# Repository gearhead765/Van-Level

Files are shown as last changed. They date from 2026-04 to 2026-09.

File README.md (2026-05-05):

# Van Level

## Overview

ESP32 Based digital level to display leveling information for a camper van. This originally started as an ESPHome application however, the requirement to have Home Assistant running on your phone or tablet in order to see the leveling information was cumbersome.  It was decided that displaying the information on a simple web page, instead of a Home Assistant Lovelace overview, would be much easier to use.  However, there is also a [Home Assistant Dashboard](HOMEASSISTANT.md) setup available.

This app displays a simple webpage with a graphic of a camper van showing the amount of wheel lift (blocking) needed under each tire to level the van.  Included is the *Van Level* app, Kicad PCB files, and Solidworks files to modify a Hammond enclosure to contain the project.

## Product Images

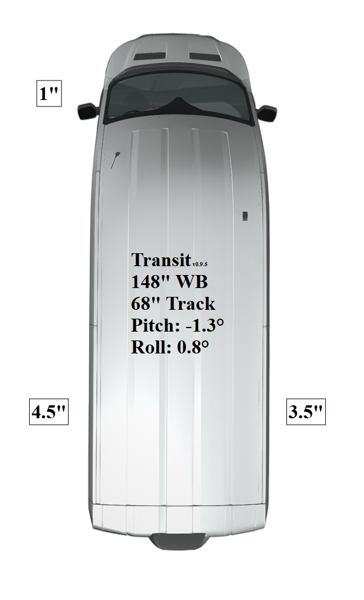
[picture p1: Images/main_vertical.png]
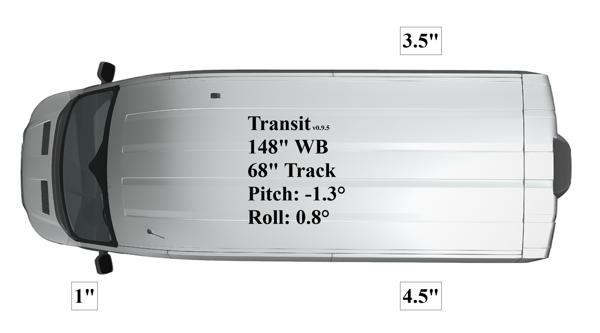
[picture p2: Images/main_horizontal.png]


## Project Structure

```
├── CAD Model/                       # SolidWorks 3D model of the board and Hammond enclosure
├── Notes/                           # Datasheets and component references
├── Van_Level_App/Van_Level          # Arduino ESP32 source code
│                 ├── data/          # App's LittleFS website
│                 │   ├── css/ 
│                 │   ├── images/
│                 │   └── js/
│                 └── HomeAssistant/ # RESTful Lovelace card for Home Assistant
├── Van_Level_PCB/                   # Kicad board files
│   └── Component Models/            # STEP files of board components
├── HARDWARE.md                      # Hardware specifications and components
├── HOMEASISTANT.md                  # Integrating with Home Assistant
├── README.md                        # This file
└── SOFTWARE.md                      # Software description
```

## [Hardware](HARDWARE.md)

## [Software](SOFTWARE.md)

## [Home Assistant](HOMEASSISTANT.md)

## Features
This application uses an ESP23 to read acceleration values from an IMU to calculate the pitch and roll values for a vehicles orientation.  These values are available via a RESTful API resource.  The ESP32's WiFi support is use to serve a self-hosted webpage to translate the pitch and roll information into leveling heights for each wheel using JavaScript.

The Wifi supports a standard network client, using either DHCP or static network setup, as well as a local Access Point for connecting directly to the device without a local network.

The leveling information can be viewed using any browser that supports Javascript. The webpage displays an image of a van, and a value next to each wheel requiring blocking.  The rounding of the height values presented can be adjusted to correspond to your leveling block height.  If you have 1" blocks, the rounding value can be set to change in 1" increments.

The van image can be changed to reflect your particular vehicle model and color, and the vehicle's wheelbase and track measurements can be edited to fit your particular van.  Details on these features are in [Software](SOFTWARE.md).

## Getting Started

### 1. Hardware Setup
1. Connect the ESP32 board to 12V DC power via connector C1 observing correct polarity
1. Connect to the built-in Access Point by opening your phone or computer Wifi Settings and selecting the `VAN_LEVEL` access point.
1. The default password for the access point is `12345678`.
1. The default name `VAN_LEVEL` and password `12345678` can be changed later.
1. Open the app webpage in any browser by navigating to the hotspot address `192.168.4.1`.
1. Your browser window should look something like this:
<br>

### 2. AP Configuration
1. To connect the *Van Level* app to your local network, or to change the default access point address, name, and/or password, we need to connect to the configuration page.  Navigate your browser to `192.168.4.1/setup`.
1. You will be asked for a login name and password.  These are the same as the AP name and password.
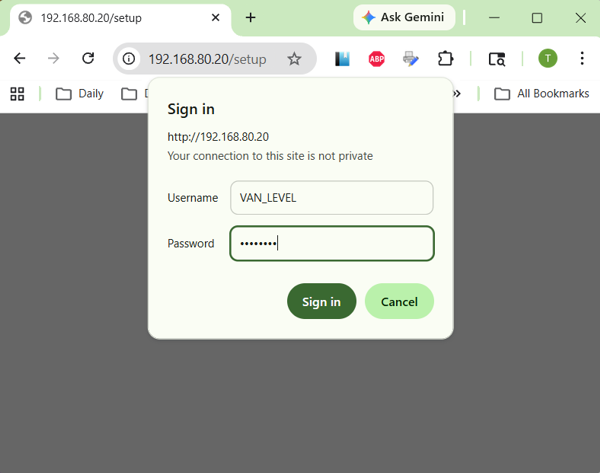
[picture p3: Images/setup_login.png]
<br>
1. After pressing `Sign in`, your browser should now be displaying the app setup page with the `status` tab selected:
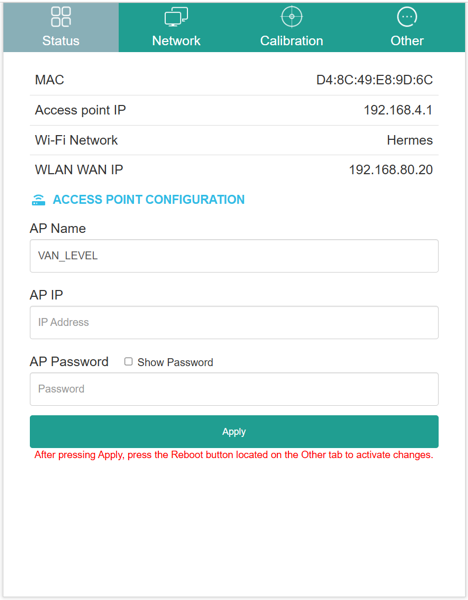
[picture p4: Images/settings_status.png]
<br>
1. On this page, you can change the Access Point name, IP address, and password.
1. The setup page name and password **are the same** as the AP name and password.  If you change the AP name and/or password on this page, remember the values so you can log into the device configuration later.

### 3. Network Configuration
1. The `Network` tab allows you to connect the *Van Level* app to your local network.  Pressing the `Scan Wi-Fi` button will search for all available access points.  When the scanning is finished, selecting the `Nearby WLAN` dropdown will present a list of all APs found allowing your to select one.
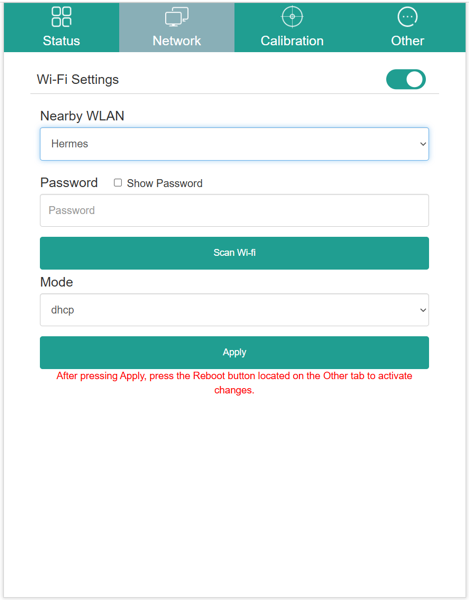
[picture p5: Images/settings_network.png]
<br>
1. You can now select DHCP or Static network configuration.  After you have made your selections and filled in the network password, click `Apply` and then reboot.
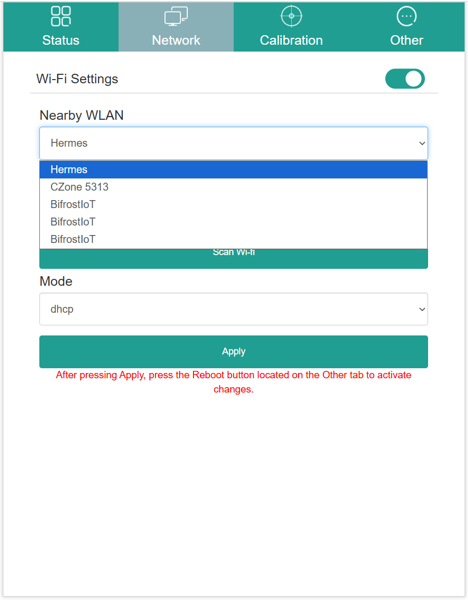
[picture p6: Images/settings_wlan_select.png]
<br>
1. After the *Van Level* device has rebooted, your should now be able to connect to the device at the assigned IP address on your network in your browser.

### 4. Calibration
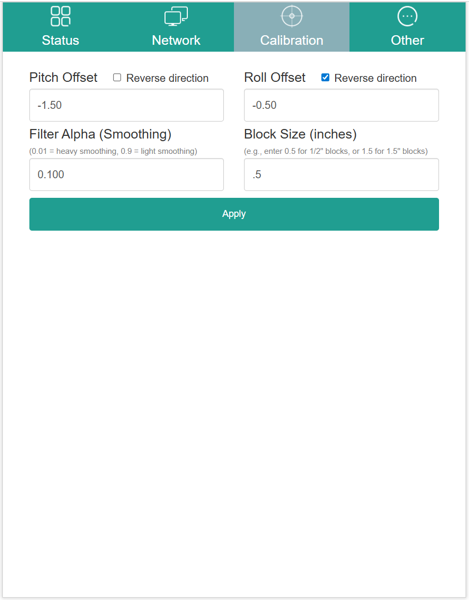
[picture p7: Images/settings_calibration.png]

1. If the pitch or roll values of you van are not `0` when the van is level, you can enter the opposite amount here to tare the display.  For example, if your van shows +1.0° pitch when level, enter -1.0 in the pitch offset box.
1. Depending on how your mount the Van Level hardware, your pitch and roll values might move in the opposite direction.  Positive pitch should be nose up, and positive roll should be clockwise looking forward (i.e. drivers side higher than the passenger side).  Select `Reverse Direction` if either of your values are opposite.
1. The `Filter Alpha` setting controls the amount of *dampening* on the pitch and roll readings. I have found a setting of `0.10` seems to be a good compromise between responsiveness and reading jitter.
1. The `Block Size` setting should be set to the smallest block thickness in your stash.  If you have plywood blocks, you might set this to `0.5` [1/2"].  If you use 2 by 12 blocks then you would set this to `1.5` [the nominal thickness of 1.5"].

### 5. Other
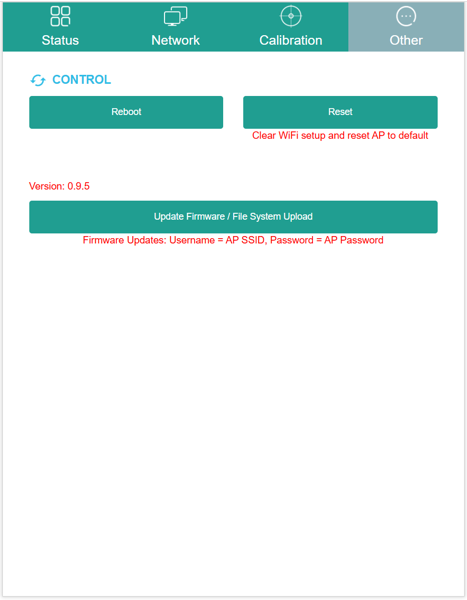
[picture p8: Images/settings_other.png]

1.  `Reboot` will restart the Van Level device retaining all of your current settings.  Use this after making coniguration changes.
1.  `Reset` will clear your stored Wifi network information and restore the default AP captive portal name and password.  **Make sure** this is what you want before pressing `Reset`.  If you have forgotten your AP name and password and can no longer access the configuration page because of this, it is possible to reset the hardware physically.  This process is discussed in [Software](SOFTWARE.md).
1. Selecting `Update Firmware / File System Upload` will allow *Over The Air* updating of the program and webpages.  See [Software](SOFTWARE.md) for more information on this process.
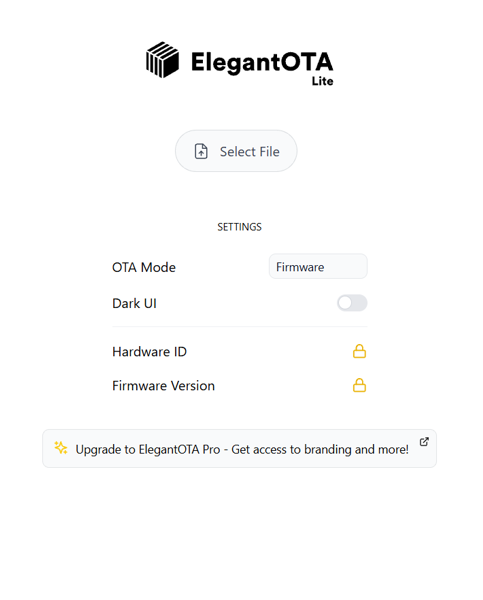
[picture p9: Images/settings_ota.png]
<br>

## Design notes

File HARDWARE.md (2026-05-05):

# Hardware

## Off the Shelf Hardware
- **Board:** [Adafruit ESP32 Huzzah Breakout](https://www.adafruit.com/product/4172)
- **IMU:**  Basic I2C 3-axis accelerometer.  Devices below have been verified to work
    - **MPU-6050:** [Adafruit MPU-6050 6-DoF Accel and Gyro Sensor - STEMMA QT Qwiic](https://www.adafruit.com/product/3886)
    - **ADXL343:** [ADXL343 - Triple-Axis Accelerometer - STEMMA QT / Qwiic](https://www.adafruit.com/product/4097)
    - **MSA311:** [Adafruit MSA311 Triple Axis Accelerometer - STEMMA QT / Qwiic](https://www.adafruit.com/product/5309)
- **Miscellaneous Components:**
    - **DC-DC Converter:** [Recom R-78E3.3-0.5](https://www.digikey.com/en/products/detail/recom-power/R-78E3-3-0-5/3593412) 
    - **Phoenix Wire Connector:** [Phoenix Mini Combicon MC 1840366](https://www.digikey.com/en/products/detail/phoenix-contact/1840366/349178) 
    - **Phoenix Board Connector:** [Phoenix Mini Combicon MC 1844210](https://www.digikey.com/en/products/detail/phoenix-contact/1844210/349195)  
    - **Polyfuse:** [1/2Amp PTC Resetable Fuse](https://www.digikey.com/en/products/detail/littelfuse-inc/1812L050-60MR/6234813) 
    - **TVS Diode:** [Littelfuse SZ5KASMC36AT3G](https://www.digikey.com/en/products/detail/littelfuse-inc/SZ5KASMC36AT3G/18716674) 
    - **Reverse Polarity Protection:** [Onsemi SS14](https://www.digikey.com/en/products/detail/onsemi/SS14/965474) 
- **Project Box:**  [Hammond 1551KFLBK](https://www.digikey.com/en/products/detail/hammond-manufacturing/1551KFLBK/2094805)
    - **Screws to Secure Board in Enclosure (2 per Project):** [#2 x 1/4" Thread-Forming Screw](https://www.mcmaster.com/products/90385a311/)
    - **3D Printed Washer (2 per Project):** [5/32"[4mm OD] x 5/64"[2mm ID] x 1/16"[1.5mm Thick]](<CAD Model/3D Printed Washer.STL>)

## Modifications to Off the Shelf Hardware
The Hammond enclosure will need a cutout for the Phoenix power connector.  The top will need a tall opening, while the bottom will need the lip removed in the connector area.  Two small washers can be 3D printed to lift the board just a little so the IMU board will clear the lid.
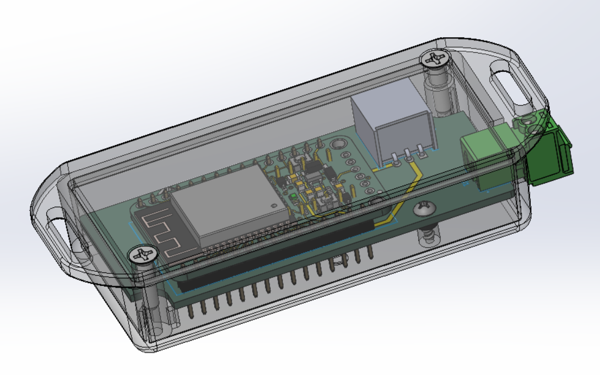
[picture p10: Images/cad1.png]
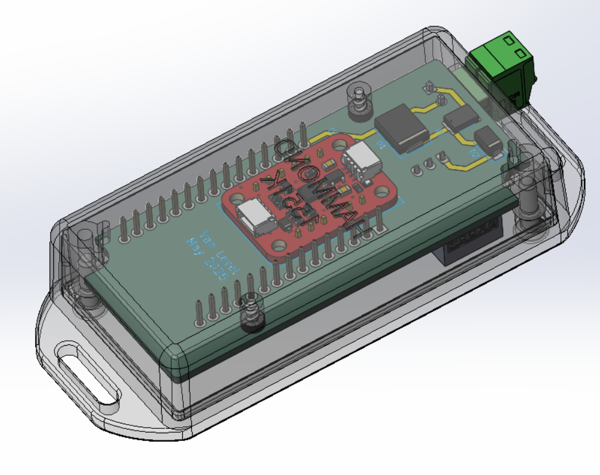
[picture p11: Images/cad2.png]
<br>

[Box cutout dimensions](<CAD Model/box_machining.pdf>)<br>
[Lid cutout dimensions](<CAD Model/lid_machining.pdf>)

## The PCB
[Kicad](https://www.kicad.org/) was used to design the very simple carrier board for the ESP32 development board and the IMU breakout board (the MPU-6050, ADXL343, and MSA311 boards from Adafruit all have the same header pinout).  This eliminated the need for point-to-point wiring and made a much more compact package possible.  You can also construct this project on strip board, dead bug style, or how ever you want.

The majority of the components are in the power supply.  Since this was for use in a vehicle, it needed to operate off of 12V.  You could easily use a power point (cigarette lighter for the older generation) to USB charger to operate the Huzzah board and then all you would need is a simple Qwicc cable to connect the Huzzah to the IMU.

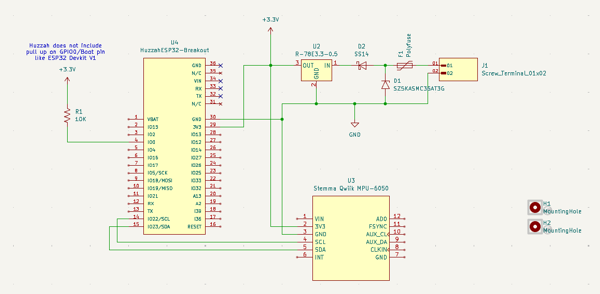
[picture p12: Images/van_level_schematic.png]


The boards were produced by [OSHPark](https://oshpark.com/shared_projects/d4r7hpFr).  You can get three boards for $20 including shipping.  They are produced in the US and usually take a couple of weeks to arrive.  Of course, all of the Kicad source files are included in the repo if you want to send them to your favorite PCB manufacturer.

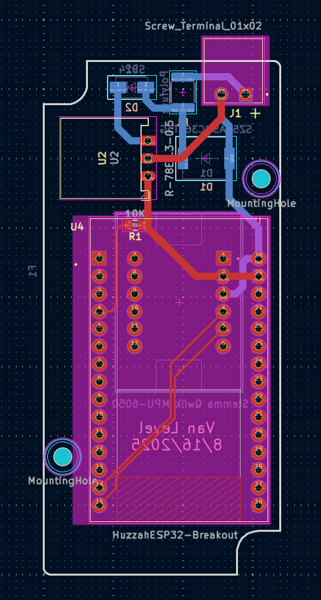
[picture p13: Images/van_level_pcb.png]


Assembly is straight forward.  Solder the lowest components first.  The Huzzah board was mounted on headers, but the IMU board was mounted directly on top of the carrier board to allow the IMU board to clear the inside of the box.

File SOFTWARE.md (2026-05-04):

# Software Development

## Introduction

This is an ESP32 application to read sensor data from a MEMS accelerometer and convert this into wheel block heights to level a camper van.  Block heights are displayed on a webpage using an image of the van roof showing the block height needed at each wheel.

Pitch and roll angles are calculated in this application running on the ESP32.  Block heights are calculated in the HTML file based on the wheelbase and track of of the van defined in the HTML file.

HomeAssistant integration is via RESTful sensor. See HomeAssistant directory for an example YAML package and Lovelace card code.

The `/setup` page allows configuration of the Access Point (default values are located in [data/APconfig.json](Van_Level_App/Van_Level/data/APconfig.json), Wifi network setup, sensor calibration, and firmware updates.

## Setting up the Arduino Environment
Included in the [Notes](Notes/) folder are numerous links to Arduino tutorials on the Web.  Among them are links to Rui & Sara Santos' [Random Nerd Tutorials](https://randomnerdtutorials.com/).  This application was based on their [ESP32 Web Server](https://randomnerdtutorials.com/esp32-web-server-gauges/) app.  Their pages will give you the necessary background on installing the Arduino IDE, Boards, and Libraries.  If you are not already familiar with these items, I highly recommend giving their tutorials some attention.

### Necessary Libraries
 - [ESPAsyncWebServer](https://github.com/ESP32Async/ESPAsyncWebServer)
 - [AsyncTCP](https://github.com/ESP32Async/AsyncTCP)
 - [Arduino_JSON](https://github.com/arduino-libraries/Arduino_JSON)
 - [ElegantOTA](https://github.com/ayushsharma82/ElegantOTA)
 - [Adafruit_BusIO](https://github.com/adafruit/Adafruit_BusIO)
 - [Adafruit_Sensor](https://github.com/adafruit/Adafruit_Sensor)
 <br>&nbsp;&nbsp;&nbsp;&nbsp;&nbsp;&nbsp;And one of the following
 - [Adafruit_ADXL343](https://github.com/adafruit/Adafruit_ADXL343)
 <br>&nbsp;&nbsp;&nbsp;&nbsp;&nbsp;&nbsp;Or
 - [Adafruit_MPU6050](https://github.com/adafruit/Adafruit_MPU6050)
 <br>&nbsp;&nbsp;&nbsp;&nbsp;&nbsp;&nbsp;Or
- [Adafruit_MSA301](https://github.com/adafruit/Adafruit_MSA301)

### IDE Enhancements
See the *Random Nerd Tutorial* above for installation instructions
 - [arduino-littlefs-upload](https://github.com/earlephilhower/arduino-littlefs-upload)
 
## The Van Level Program
As previously mentioned, the program is structured along the lines of *Random Nerd Tutorial's* [ESP32 Web Server](https://randomnerdtutorials.com/esp32-web-server-gauges/). The beginning starts with the global variable declarations, followed by functions to initialize our IMU sensor and retrieve data from it.

Our program sets up a local Access Point with the default SSID `VAN_LEVEL` that we will use to configure the WiFi access.  We have a single event listener to watch for Access Point connection requests and limit to a single connection.

The program actually begins in the `setup()` function where we start by setting up our local file system using LittleFS, and open the file [data/APconfig.json](Van_Level_App/Van_Level/data/APconfig.json) containing our default AP configuration information used to log into the captive Access Point.

At this point in the setup process, there is a 3-second pause to allow the `Boot` button on the ESP board to be pressed.  If pressed, this will erase the saved preferences in EEPROM.  Useful if you have customized the AP information and subsequently forgotten it.

Next, we retrieve our AP and Wifi configuration and our calibration values from the ESP32's non-volatile EEPROM storage.  This storage area is retained across restarts and power loss.  If there are no saved values, default values are substituted.

With the saved AP and Wifi information retrieved, or default values substituted, we proceed to configure our HTML query handlers.  Our Web server has two pages that it delivers to the user.  `Index` and `Setup`; both stored in the [data/](Van_Level_App/Van_Level/data/) directory.  `Index` is our default web page displaying a top-down image of a van with block heights next to the wheel locations.  `Setup` is the page where we can modify the default AP SSID and password, and/or connect to a local WiFi network, and adjust our calibration values.

One of the query handlers is a RESTful API that is the meat of our application.  We send our lightly processed IMU data as a JSON response to registered API listeners.  The raw IMU data is converted to pitch and roll angles using floating point math to take advantage of the EPS32's built-in FPU.  These pitch and roll values are processed with a low pass filter (an Exponential Moving Average), adjusted based on the calibration settings, and then served to listeners.

With our handlers in place, we establish our WiFi connection, and then sit by and listen for requests to serve pages and data.
 
## Programming the ESP32
### Initial Programming
The initial programming of the ESP32 development board will require a USB/TTL programmer like the [SH-U09C5 USB to TTL UART](https://www.amazon.com/DSD-TECH-SH-U09C5-Converter-Support/dp/B07WX2DSVB) since the Feather board does not have built-in USB support.  Once the initial program and LittleFS have been installed the first time, you can then use the application setup page and the Elegant OTA features to remote load your updates Over-The-Air.
### Firmware OTA updates:
Using the Arduino IDE, firmware updatess are created by selecting "Sketch>Export Compiled Binary". The generated file will be saved under your project folder inside a Build folder then a series of other folders. The file with the `.ino.bin` extension is the one you should upload to your board using the ElegantOTA web page.

### LittleFS OTA updates:
Again using the Arduino IDE, you will need the programmer connected, but not the board. Press `[Ctrl]` + `[Shift]` + `[P]` to open the command palette. Select `Upload Little FS to Pico/ESP8266/ESP32`. You'll get an error because there isn't any ESP32 board connected – don't worry, it will still create a .bin file from the data folder.  In the debugging window you'll see the `.littlefs.bin` file location.  Probably in "C:\Users\<username>\AppData\Local\Temp\".
  
  ## Acknowledgements
  
```
Portions of this app are based on Random Nerd Tutorials
  https://randomnerdtutorials.com/
  Permission is hereby granted, free of charge, to any person obtaining a copy of this
  software and associated documentation files. The above copyright notice and this
  permission notice shall be included in all copies or substantial portions of the Software.

Portions of this app are based on Configuration-webpage-esp32 
  https://github.com/futechiot/Configuration-webpage-esp32
  GNU GENERAL PUBLIC LICENSE Version 3, 29 June 2007
```

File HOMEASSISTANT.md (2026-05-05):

# Integrating with Home Assistant
## Introduction
Since The Van Level app is basically a RESTful API, to integrate with Home Assistant, all that is needed is to create a sensor to request data periodically from the REST API, and create a Dashboard card to display that information.
## Configuring Home Assistant
### Edit `configuration.yaml`
The first step is to turn on [packages](https://www.home-assistant.io/docs/configuration/packages/) in Home Assistant. Edit Home Assistant's configuration file `configuration.yaml` located in the `config/` directory.  You need to add the following line to the `homeassistant:` key:
```
    homeassistant:
      packages: !include_dir_named packages
```
You may need to create the directory `packages/` under your Home Assistant's `config/` directory if it doesn't already exist.
### The Van Image
Create the `www/` directory under `config/` if it does not already exist and copy the [van picture](Van_Level_App/Van_Level/HomeAssistant/van_top_view.png) into the `config/www/` directory.
### The REST sensor
Place the [van_leveling.yaml](Van_Level_App/Van_Level/HomeAssistant/van_leveling.yaml) file into the `/config/packages/` directory in Home Assistant.  There is only a single edit to this file needed to customize it to your specific installation. At the top of the file you will see the following:

```
  - platform: rest
    name: "Van Level Data"
    resource: http://YOUR_IP_HERE/readings   <=== EDIT THIS
    method: GET
    scan_interval: 1
    value_template: "{{ value_json.pitch }}"  # required, even if we only use attributes
 ```
 Replace the words `YOUR_IP_HERE` with the IP address of your Van Level device.  You can also adjust the `scan_interval` if you desire.  Setting this to a larger value will reduce the traffic on your network, but will also reduce the *responsiveness* of the Dashboard card.
 
 ### The Dashboard Card
 Copy the contents of [van_leveling_lovelace.yaml](Van_Level_App/Van_Level/HomeAssistant/van_leveling_lovelace.yaml) to your Dashboard. You can add this to the dashboard via the Raw Configuration Editor or through the YAML mode.  I suggest creating a new dashboard tab and adding this all by itself.

 ### Restarting Home Assistant
 
 Once the necessary changes have all been made, click on [Developer Tools](https://www.home-assistant.io/docs/tools/dev-tools/), select the `YAML` tap and click `CHECK CONFIGURATION`.  If you get a confirmation that the configuration is good, click `RESTART`, and choose restart Home Assistant.
 
 ### Your Van Level Dashboard
 Hopefully, you now have a working Van Level display on your Home Assistant dashboard.
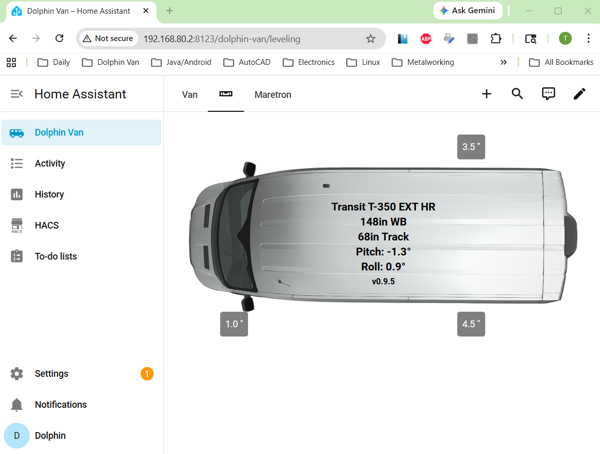
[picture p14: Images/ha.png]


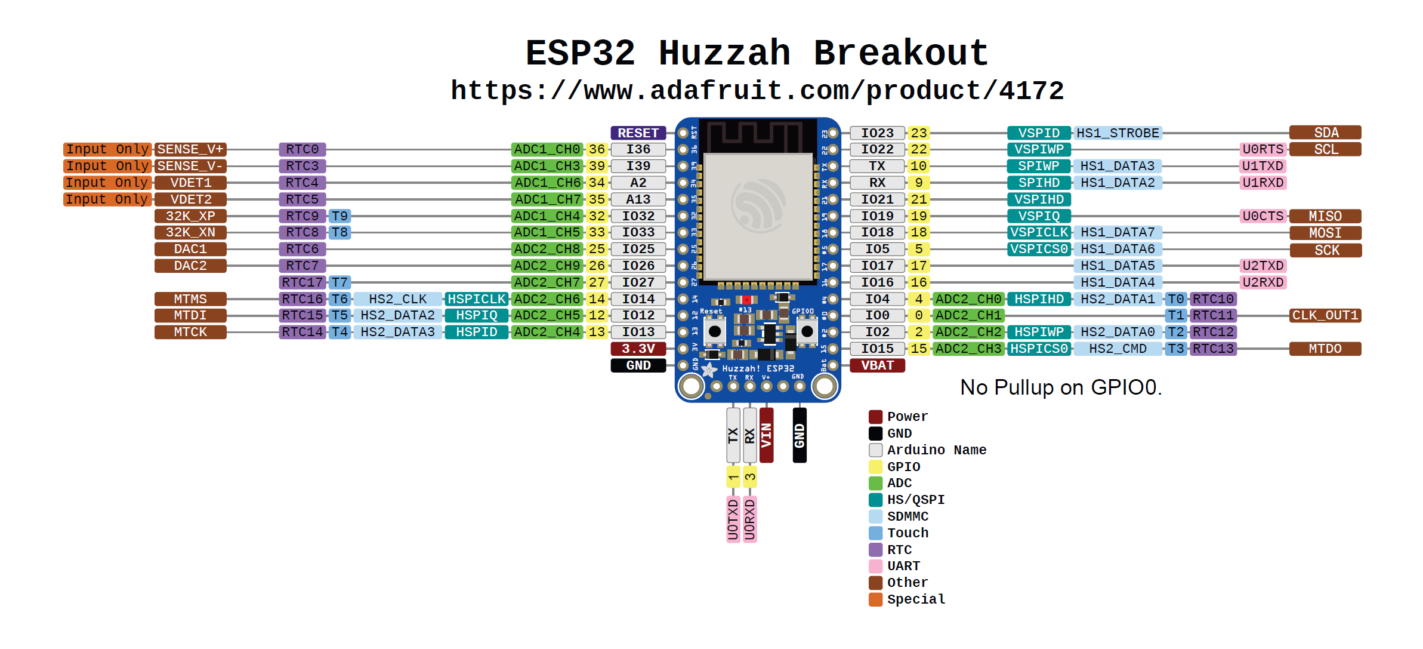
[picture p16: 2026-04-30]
Notes/Pinout Adafruit ESP32 Huzzah.png

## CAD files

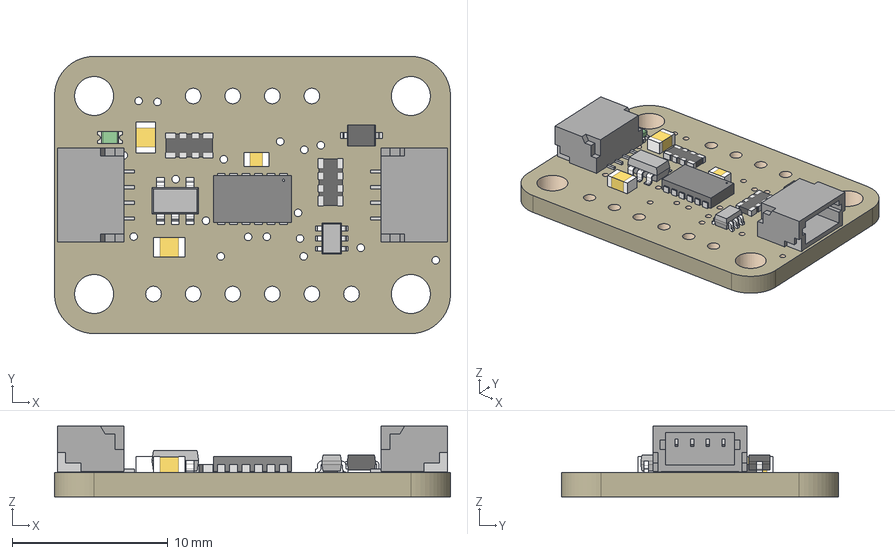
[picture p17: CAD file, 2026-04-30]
Van_Level_PCB/Component Models/Adafruit ADXL343 STEMMA QT.STEP
25.4 x 17.8 x 4.53 mm
Board
10uF
AP2112K-3.3
10uF_1
0.1uF
10K x 2
BSS138
STEMMA_I2C_QT x 2
GREEN
1N4148
ADXL343

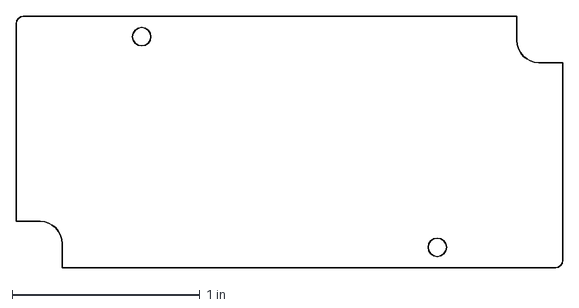
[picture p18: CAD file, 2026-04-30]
CAD Model/1551KFL Board.DXF
2.91 x 1.34 in

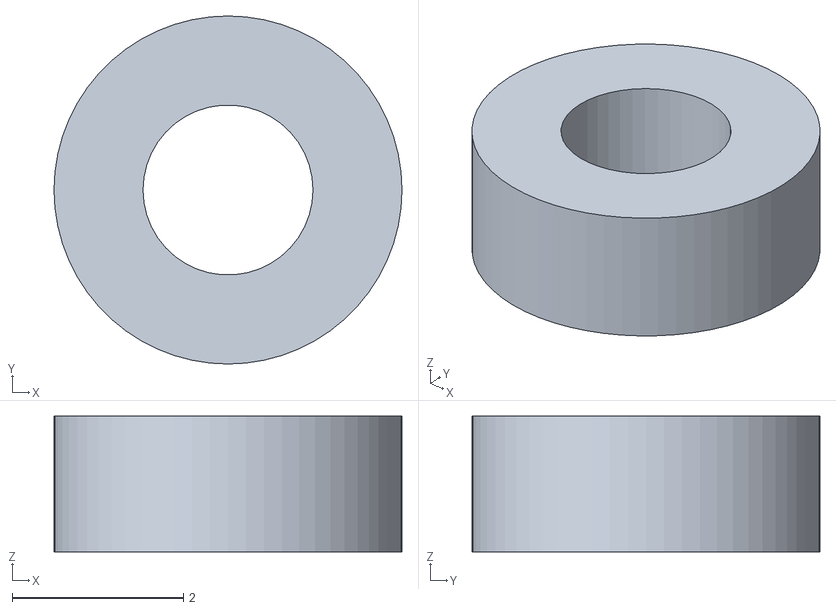
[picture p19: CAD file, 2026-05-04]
CAD Model/3D Printed Washer.STL
4.06 x 4.06 x 1.59

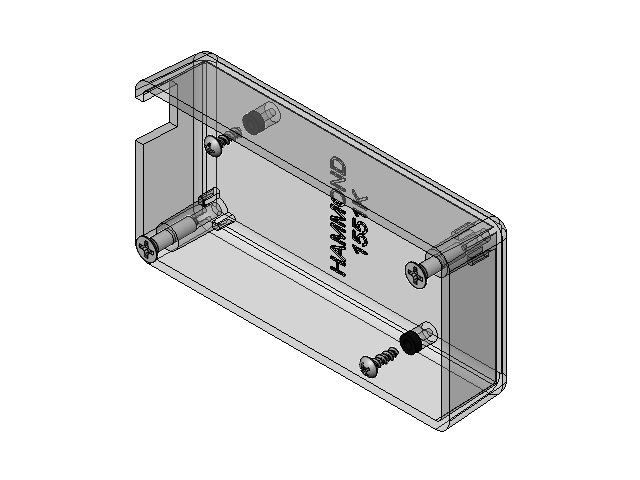
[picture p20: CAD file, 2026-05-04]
CAD Model/1551KFL.SLDASM
1551K Box^1551KFL
SC510 (screw #4X 1_2''FH)^1551KFL x 2
90385A312_Rounded Head Thread-Forming Screws^1551KFL x 2
3D Printed Washer^1551KFL x 2

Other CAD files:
CAD Model/wheel lift napkin sketch.SLDPRT

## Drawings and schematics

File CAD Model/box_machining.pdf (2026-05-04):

B B

2

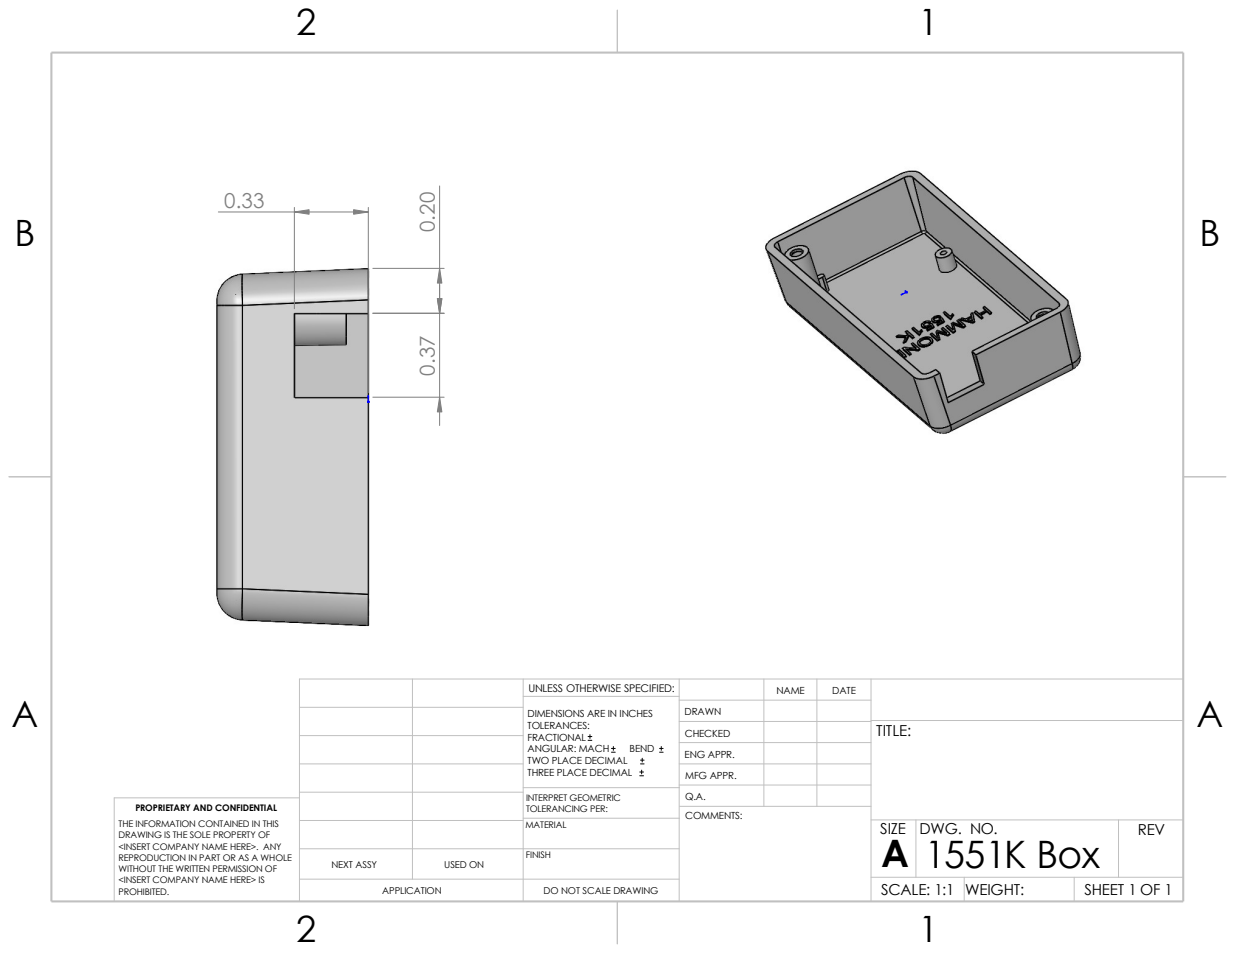
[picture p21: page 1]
COMMENTS:

UNLESS OTHERWISE SPECIFIED: | | NAME | DATE

DIMENSIONS ARE IN INCHES TOLERANCES: FRACTIONAL ANGULAR: MACH BEND TWO PLACE DECIMAL THREE PLACE DECIMAL | DRAWN

CHECKED | | | TITLE:

ENG APPR.
MFG APPR.

INTERPRET GEOMETRIC TOLERANCING PER: | Q.A.
MATERIAL | | SIZE A | DWG. NO. 1551K Box | REV

PROPRIETARY AND CONFIDENTIAL
THE INFORMATION CONTAINED IN THIS
DRAWING IS THE SOLE PROPERTY OF
<INSERT COMPANY NAME HERE>. ANY
REPRODUCTION IN PART OR AS A WHOLE
WITHOUT THE WRITTEN PERMISSION OF
<INSERT COMPANY NAME HERE> IS
PROHIBITED.

NEXT ASSY | USED ON | FINISH

APPLICATION | DO NOT SCALE DRAWING | | SCALE: 1:1 | WEIGHT: | SHEET 1 OF 1

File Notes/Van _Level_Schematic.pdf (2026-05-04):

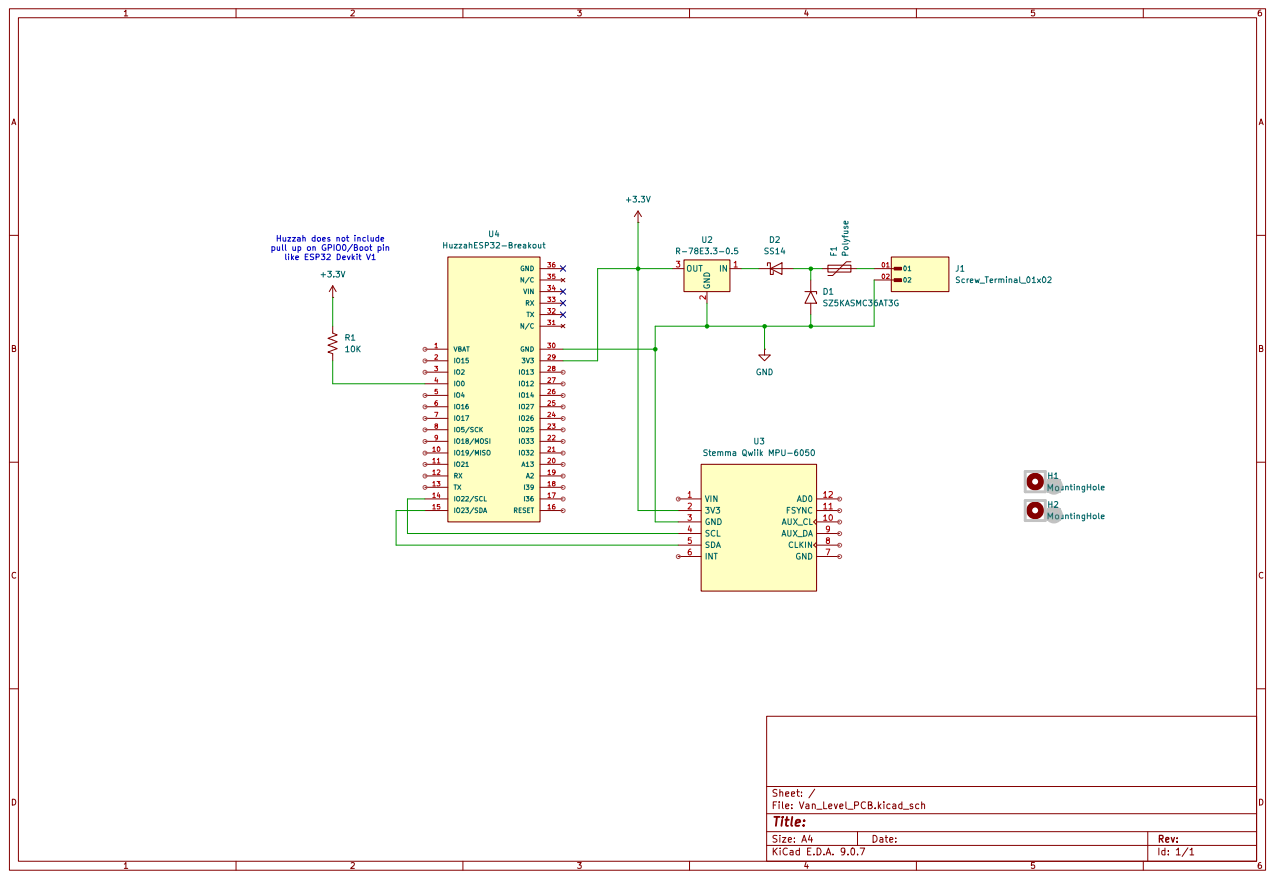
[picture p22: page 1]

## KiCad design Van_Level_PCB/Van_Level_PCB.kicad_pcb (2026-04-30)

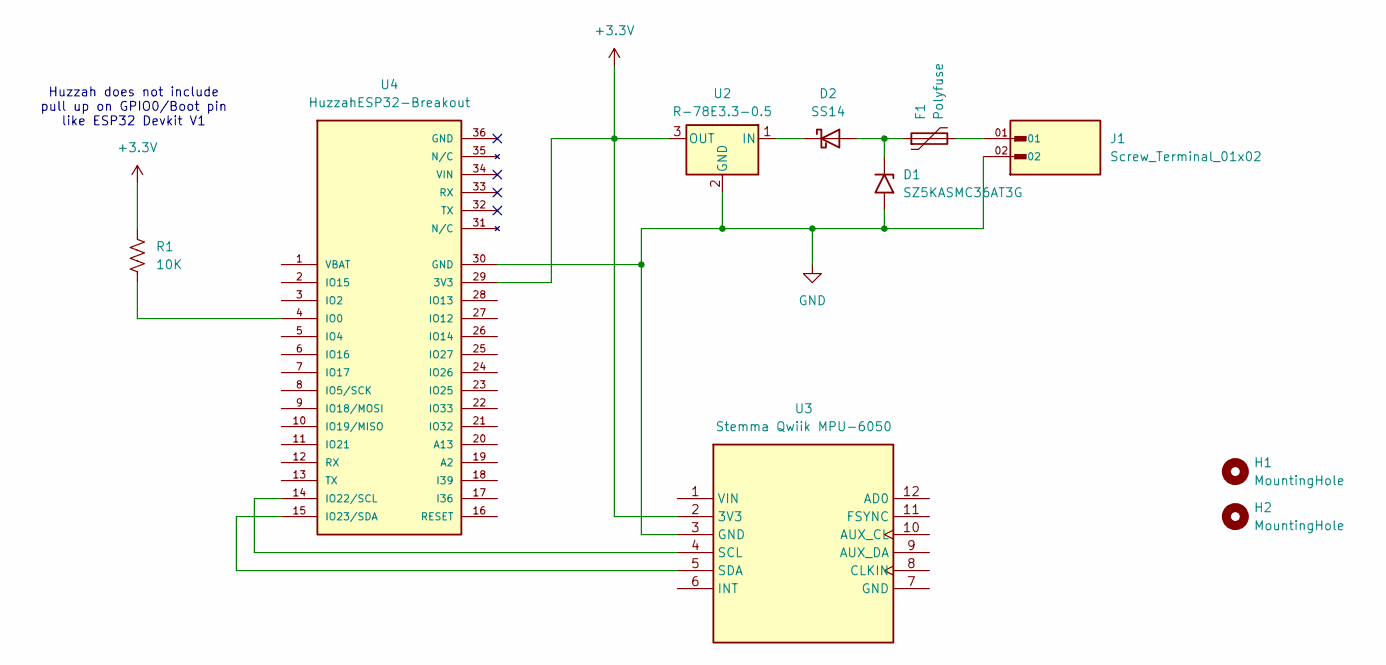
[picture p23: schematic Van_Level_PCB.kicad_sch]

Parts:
D1: SZ5KASMC36AT3G; ST_D_SMC
D2: SS14; D_SMA
F1: Polyfuse; Fuse_1812_4532Metric_Pad1.30x3.40mm_HandSolder
H1, H2: MountingHole; MountingHole_2.5mm
J1: Screw_Terminal_01x02; PHOENIX_1844210; PARTREV 02.08.2023
R1: 10K; R_0805_2012Metric_Pad1.20x1.40mm_HandSolder
U2: R-78E3.3-0.5; Converter_DCDC_RECOM_R-78E-0.5_THT_Horizontal
U3: Stemma Qwiik MPU-6050; Stemma Qwiik 0.5_ x 0.8_ 6+6-pin
U4: HuzzahESP32-Breakout; HUZZAH32_Breakout; PARTREV N/A

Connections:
+3.3V: R1.1, U2.3 (OUT), U3.2 (3V3), U4.29 (3V3)
GND: D1.2 (A2), J1.02, U2.2 (GND), U3.3 (GND), U4.30 (GND)
unnamed: D1.1 (A1), D2.2 (A), F1.1
unnamed: D2.1 (K), U2.1 (IN)
unnamed: F1.2, J1.01
unnamed: U3.4 (SCL), U4.14 (IO22/SCL)
unnamed: U3.5 (SDA), U4.15 (IO23/SDA)
unnamed: R1.2, U4.4 (IO0)

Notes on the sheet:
Huzzah does not include pull up on GPIO0/Boot pin like ESP32 Devkit V1

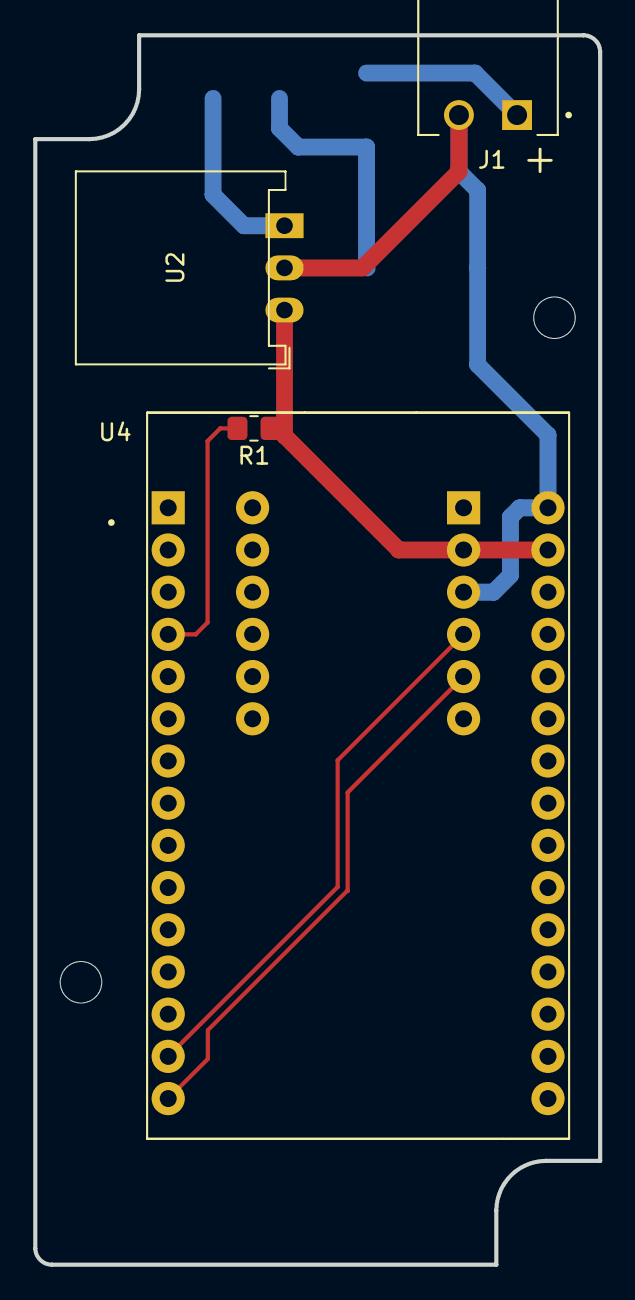
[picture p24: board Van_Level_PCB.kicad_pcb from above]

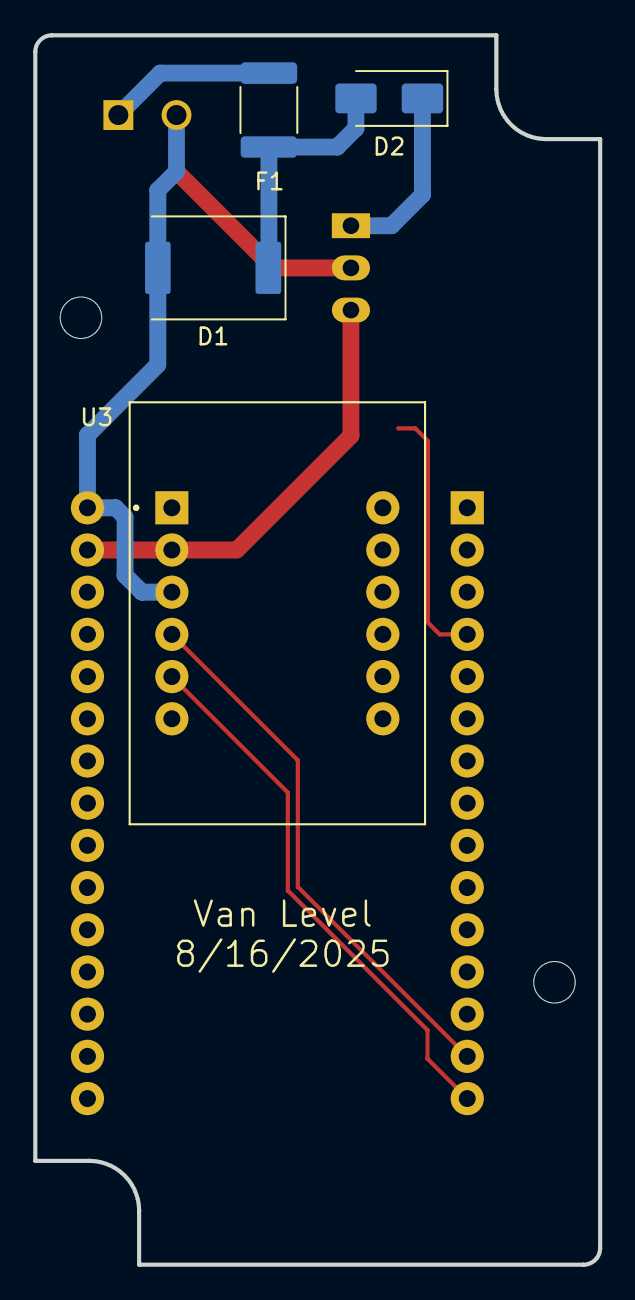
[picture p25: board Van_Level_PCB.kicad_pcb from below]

Board: 2 copper layers, 34.0 x 74.0 mm, 10 parts (4 on the bottom side), 8 nets.

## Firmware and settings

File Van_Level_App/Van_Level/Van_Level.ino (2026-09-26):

/*******************************************************************************************
 Van Level display

    ESP32 application to read sensor data from a MEMS accelerometer and convert this into
    wheel block heights to level a camper van.  Block heights are displayed on a webpage
    using an image of the van roof showing the block height needed at each wheel.

    Pitch and roll angles are calculated in this application running on the ESP32.
    Block heights are calculated in the HTML file based on the wheelbase and track of
    of the van defined in the HTML file.

    HomeAssistant integration is via RESTful sensor. See HomeAssistant directory for
    an example YAML package and Lovelace card code.

    The /setup page allows configuration of the Access Point (default values are located
    in /data/APconfig.json), Wifi network setup, sensor calibration, and firmware updates.

    Firmware OTA updates:
      Firmware .bin files are created by selecting "Sketch>Export Compiled Binary"
      The generated file will be saved under your project folder inside a Build
      folder then a series of other folders. The file with the .ino.bin extension
      is the one you should upload to your board using the ElegantOTA web page.

    LittleFS OTA updates:
      You will need the programmer conected, but not the board.
      Press [Ctrl] + [Shift] + [P] to open the command palette.
      Select "Upload Little FS to Pico/ESP8266/ESP32".
      You'll get an error because there isn't any ESP32 board connected – don't worry,
      it will still create a .bin file from the data folder.  In the debugging window you'll
      see the .littlefs.bin file location.  Probably in "C:\Users\<username>\AppData\Local\Temp\".

********************************************************************************************

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
    Portions of this app are based on Configuration-webpage-esp32 
      https://github.com/futechiot/Configuration-webpage-esp32
      GNU GENERAL PUBLIC LICENSE Version 3, 29 June 2007

*******************************************************************************************/

#include <Arduino.h>
#include <WiFi.h>
#include <ESPAsyncWebServer.h>
#include <LittleFS.h>
#include <Arduino_JSON.h>
#include <Preferences.h>
#include <Math.h>
#include <Adafruit_Sensor.h>
#include <ElegantOTA.h>

// Comment out to show plain text passwords in serial monitor
#define HIDE_PASSWORDS

// Uncomment whichever IMU sensor is connected to ESP32 I2C
//   (GPIO 23 = SDA(Qwiic blue), GPIO 22 = SCL(Qwiic yellow))
//#define MPU6050
#define ADXL343

#if defined(MPU6050)
  #include <Adafruit_MPU6050.h>
#elif defined(ADXL343)
  #include <Adafruit_ADXL343.h>
#endif

const char* VERSION = "1.0.2";

// SoftAP configuration
const char * s_configFile = "/APconfig.json"; // SoftAP configuration defaults
String wsid;
String wpass;
String esid;
String epass;
String password;
String myIP;
String localIP;
bool apConnected = false;
JSONVar configJSON;

// EEPROM storage for configuration values
Preferences preferences;

// Calibration variables
float pOffset;
int pInvert;
float rOffset;
int rInvert;
float pTolerance = 1.0f;  // "level" if within tolerance degrees
float rTolerance = 1.0f;
float blockFraction = 2.0f;  // default to 1/2" block heights

// Timer variables
unsigned long bootStart = 0;  // if non-zero, will restart when bootStart + bootDelay = now
const unsigned long bootDelay = 5000;
unsigned long lastWebTime = 0; // IMU data webpage push
const unsigned long webDelay = 1000; // refresh webpage every second
unsigned long lastSensorReadTime = 0;
unsigned long sensorReadDelay = 40000; // microseconds. 25Hz default
unsigned long lastWifiCheck = 0;
const unsigned long wifiCheckInterval = 15000; // Check connection status every 15 seconds

// IMU filtering (Exponential Moving Average)
float filteredPitch = 0.0f;
float filteredRoll = 0.0f;
float alpha = 0.1f; // adjust this between 0.01 (heavy smoothing) and 0.9 (light smoothing)

// Create a sensor object for our MEMS accelerometer
#if defined(MPU6050)
  Adafruit_MPU6050 imuSensor;
#elif defined(ADXL343)
  Adafruit_ADXL343 imuSensor = Adafruit_ADXL343(12345);
#endif
JSONVar imuData; // json variable to hold sensor readings
bool hasIMU = false;

// Webserver pieces
AsyncWebServer server(80);
AsyncEventSource events("/events");

// Function to initialize IMU Sensor MPU-6050/ADXL343
void initSensor() {
  #if defined(MPU6050)
    Serial.println("Looking for MPU6050 IMU");
  #elif defined(ADXL343)
    Serial.println("Looking for ADXL343 IMU");
  #endif
 
  if (!imuSensor.begin()) {
    Serial.println("Could not find a valid IMU sensor, check wiring!");
    hasIMU = false;
  }
  else {
    hasIMU = true;
    #if defined(MPU6050)
      imuSensor.setAccelerometerRange(MPU6050_RANGE_2_G);
      Serial.print("Accelerometer range set to: ");
      switch (imuSensor.getAccelerometerRange()) {
        case MPU6050_RANGE_2_G:
          Serial.print("±2");
          break;
        case MPU6050_RANGE_4_G:
          Serial.print("±4");
          break;
        case MPU6050_RANGE_8_G:
          Serial.print("±8");
          break;
        case MPU6050_RANGE_16_G:
          Serial.print("±16");
          break;
        default:
          Serial.print("??");
          break;
      }
      Serial.println("G");

      imuSensor.setFilterBandwidth(MPU6050_BAND_21_HZ);
      Serial.print("Filter bandwidth set to: ");
      // confirm data rate and sync polling delay
      switch (imuSensor.getFilterBandwidth()) {
        case MPU6050_BAND_260_HZ:
          Serial.print("260");
          sensorReadDelay = 1000000/260;
          break;
        case MPU6050_BAND_184_HZ:
          Serial.print("184");
          sensorReadDelay = 1000000/184;
          break;
        case MPU6050_BAND_94_HZ:
          Serial.print("94");
          sensorReadDelay = 1000000/94;
          break;
        case MPU6050_BAND_44_HZ:
          Serial.print("44");
          sensorReadDelay = 1000000/44;
          break;
        case MPU6050_BAND_21_HZ:
          Serial.print("21");
          sensorReadDelay = 1000000/21;
          break;
        case MPU6050_BAND_10_HZ:
          Serial.print("10");
          sensorReadDelay = 1000000/10;
          break;
        case MPU6050_BAND_5_HZ:
          Serial.print("5");
          sensorReadDelay = 1000000/5;
          break;
        default:
          Serial.println("??");
          break;
      }
      Serial.println("Hz");

    #elif defined(ADXL343)
      imuSensor.setRange( ADXL343_RANGE_2_G);
      Serial.print( "Accelerometer range set to: ");
      switch ( imuSensor.getRange()) {
        case ADXL343_RANGE_2_G:
          Serial.print("±2");
          break;
        case ADXL343_RANGE_4_G:
          Serial.print("±4");
          break;
        case ADXL343_RANGE_8_G:
          Serial.print("±8");
          break;
        case ADXL343_RANGE_16_G:
          Serial.print("±16");
          break;
        default:
          Serial.print("??");
          break;
      }
      Serial.println("G");
      
      imuSensor.setDataRate( ADXL343_DATARATE_25_HZ);
      Serial.print( "Data rate set to: ");
      // confirm data rate and sync polling delay
      switch(imuSensor.getDataRate()) {
        case ADXL343_DATARATE_3200_HZ:
          Serial.print("3200");
          sensorReadDelay = 1000000/3200;
          break;
        case ADXL343_DATARATE_1600_HZ:
          Serial.print("1600");
          sensorReadDelay = 1000000/1600;
          break;
        case ADXL343_DATARATE_800_HZ:
          Serial.print("800");
          sensorReadDelay = 1000000/800;
          break;
        case ADXL343_DATARATE_400_HZ:
          Serial.print("400");
          sensorReadDelay = 1000000/400;
          break;
        case ADXL343_DATARATE_200_HZ:
          Serial.print  ("200");
          sensorReadDelay = 1000000/200;
          break;
        case ADXL343_DATARATE_100_HZ:
          Serial.print("100");
          sensorReadDelay = 1000000/100;
          break;
        case ADXL343_DATARATE_50_HZ:
          Serial.print("50");
          sensorReadDelay = 1000000/50;
          break;
        case ADXL343_DATARATE_25_HZ:
          Serial.print("25");
          sensorReadDelay = 1000000/25;
          break;
        case ADXL343_DATARATE_12_5_HZ:
          Serial.print("12.5");
          sensorReadDelay = 1000000/12.5;
          break;
        case ADXL343_DATARATE_6_25HZ:
          Serial.print("6.25");
          sensorReadDelay = 1000000/6.25;
          break;
        case ADXL343_DATARATE_3_13_HZ:
          Serial.print("3.13");
          sensorReadDelay = 1000000/3.13;
          break;
        case ADXL343_DATARATE_1_56_HZ:
          Serial.print("1.56");
          sensorReadDelay = 1000000/1.56;
          break;
        case ADXL343_DATARATE_0_78_HZ:
          Serial.print("0.78");
          sensorReadDelay = 1000000/0.78;
          break;
        case ADXL343_DATARATE_0_39_HZ:
          Serial.print("0.39");
          sensorReadDelay = 1000000/0.39;
          break;
        case ADXL343_DATARATE_0_20_HZ:
          Serial.print("0.20");
          sensorReadDelay = 1000000/0.2;
          break;
        case ADXL343_DATARATE_0_10_HZ:
          Serial.print("0.10");
          sensorReadDelay = 1000000/0.1;
          break;
        default:
          Serial.print("??");
          break;
      }
      Serial.println("Hz");
    #endif
  }
}

// Function to constantly poll the IMU and apply the EMA filter
void updateSensorData() {
  if (hasIMU) {
    float rawPitch = 0; // changed from double
    float rawRoll = 0;  // changed from double

    #if defined(MPU6050)
      sensors_event_t a, g, temp;
      imuSensor.getEvent(&a, &g, &temp);
      
      // rawPitch = (atan(a.acceleration.x / sqrt(sq(a.acceleration.y) + sq(a.acceleration.z)))) * 180/PI;
      // rawRoll = (atan(a.acceleration.y / sqrt(sq(a.acceleration.x) + sq(a.acceleration.z)))) * 180/PI;
      
      // optimized float calculations instead of doubles above to utilize the ESP32 hardware floating point unit
      rawPitch = atan2f(a.acceleration.x, sqrtf(a.acceleration.y * a.acceleration.y + a.acceleration.z * a.acceleration.z)) * 57.29577951f;
      rawRoll = atan2f(a.acceleration.y, sqrtf(a.acceleration.x * a.acceleration.x + a.acceleration.z * a.acceleration.z)) * 57.29577951f;
      
    #elif defined(ADXL343)
      sensors_event_t event;
      imuSensor.getEvent(&event);
      
      // rawPitch = (atan(event.acceleration.x / sqrt(sq(event.acceleration.y) + sq(event.acceleration.z)))) * 180/PI;
      // rawRoll = (atan(event.acceleration.y / sqrt(sq(event.acceleration.x) + sq(event.acceleration.z)))) * 180/PI;
      
      // optimized float calculations instead of doubles above to utilize the ESP32 hardware floating point unit
      rawPitch = atan2f(event.acceleration.x, sqrtf(event.acceleration.y * event.acceleration.y + event.acceleration.z * event.acceleration.z)) * 57.29577951f;
      rawRoll = atan2f(event.acceleration.y, sqrtf(event.acceleration.x * event.acceleration.x + event.acceleration.z * event.acceleration.z)) * 57.29577951f;
    #endif

    // apply the Exponential Moving Average (EMA) filter
    filteredPitch = (alpha * rawPitch) + ((1.0f - alpha) * filteredPitch);
    filteredRoll = (alpha * rawRoll) + ((1.0f - alpha) * filteredRoll);
  }
}

// Function to grab the latest filtered data, apply calibration, and output JSON
String getSensorReadings() {
  float finalPitch = 0;
  float finalRoll = 0;

  if (hasIMU) {
    // apply calibration values to the continuously filtered data
    finalPitch = (filteredPitch + pOffset) * pInvert;
    finalRoll = (filteredRoll + rOffset) * rInvert;
  }

  imuData["pitch"] = String(finalPitch, 1);
  imuData["roll"] = String(finalRoll, 1);
  imuData["ver"] = String(VERSION);
  imuData["fraction"] = String(blockFraction, 3);

  bool isLevel = (fabsf(finalPitch) <= pTolerance) && (fabsf(finalRoll) <= rTolerance);
  imuData["lvl"] = isLevel;
  
  Serial.print("Filtered Pitch: ");
  Serial.print(finalPitch);
  Serial.print(", Filtered Roll: ");
  Serial.print(finalRoll);
  Serial.println("");

  String jsonString = JSON.stringify(imuData);
  return jsonString;
}

// Function to watch for connection events
void WiFiEvent(WiFiEvent_t event, WiFiEventInfo_t info) {
  // We only want one SoftAP connection. For basic security, we rely
  // on the AP password to limit who can change our configuration.
  switch (event) {
    case ARDUINO_EVENT_WIFI_AP_STADISCONNECTED:
      apConnected = false;
      Serial.println("SoftAP client disconnected");
      break;
    case ARDUINO_EVENT_WIFI_AP_STAIPASSIGNED:
      apConnected = true;
      Serial.println("SoftAP client connected");
      break;
      
    // grab our assigned IP when connecting to a network
    case ARDUINO_EVENT_WIFI_STA_START:
      Serial.println("Wi-Fi Station started. Connecting...");
      break;
    case ARDUINO_EVENT_WIFI_STA_GOT_IP:
      Serial.print("Successfully connected to router! IP: ");
      localIP = WiFi.localIP().toString();
      Serial.println(localIP);
      break;
    case ARDUINO_EVENT_WIFI_STA_DISCONNECTED:
      Serial.println("Lost connection to router. Background auto-reconnect active...");
      localIP = "Not Connected";
      break;
    default:
      break;
  }
}
  
//####################################  BEGIN SETUP  ##################################
void setup() {
  Serial.begin(115200);
  initSensor();

  // connect to EEPROM storage
  if (!preferences.begin("config", false)) {
    Serial.println("Failed to initialise Preferences");
    while (1);
  }
  Serial.println("Preferences initialized");

  // mount our file server for our static data and web pages
  if (!LittleFS.begin()) {
    Serial.println("An error has occurred while mounting LittleFS");
    while (1);
  }
  Serial.println("LittleFS successfully mounted");

  // get default SoftAP configuration from file
  File dataFile = LittleFS.open(s_configFile, FILE_READ); //Open File for reading
  if (!dataFile) {
    Serial.println("Config file open failed on read.");
    while (1);
  } else {
    String configContents;
    Serial.println("Reading configuration data from file:");
    if (dataFile.available()) configContents = dataFile.readString();
    dataFile.close();
    #ifdef HIDE_PASSWORDS
      Serial.println( "*Hidden*");
    #else
      Serial.println(configContents);
    #endif

    configJSON = JSON.parse(configContents);
    if (JSON.typeof(configJSON) == "undefined") {
      Serial.println("Parsing Config failed!");
      while (1);
    }
  }

  // reset board to defaults if necessary (i.e. lost password)
  //  click EN/RESET button, then press and hold BOOT/GPIO0 button for 5 seconds
  //  careful with Adafruit Huzzah ESP32 breakout board, it does not come with 
  //  pull-up on GPIO0 like the Devkit V1 boards - you need to add it, or use INPUT_PULLUP.
  //  select the INPUT version below if you have an external pullup resistor.
  pinMode( 0, INPUT_PULLUP);
  //pinMode( 0, INPUT);
 
  Serial.println( "Hold \"BOOT\" button to reset board to defaults");
  delay(3000);
  if (digitalRead( 0) == LOW) { // button is pulled high on hardware, pressing it makes it low
    Serial.println( "Resetting, release \"BOOT\" button now");
    preferences.clear();
  }

  // retrieve EEPROM sensor calibration values
  pOffset = preferences.getFloat("pOffset", 0.0);
  rOffset = preferences.getFloat("rOffset", 0.0);
  pInvert = preferences.getInt("pInvert", 1);
  rInvert = preferences.getInt("rInvert", 1);
  alpha = preferences.getFloat("alpha", 0.1f); // defaults to 0.1 if not set
  blockFraction = preferences.getFloat("fraction", 2.0f); // defaults to 1/2" blocks
  pTolerance = preferences.getFloat("pTolerance", 0.15f);
  rTolerance = preferences.getFloat("rTolerance", 0.15f); 
  
  Serial.print("Stored Calibration values: pOffset=");
  Serial.print(pOffset);
  Serial.print(" pInvert=");
  Serial.print(pInvert);
  Serial.print(" rOffset=");
  Serial.print(rOffset);
  Serial.print(" rInvert=");
  Serial.print(rInvert);
  Serial.print(" alpha=");
  Serial.print(alpha);
  Serial.print(" fraction=");
  Serial.print(blockFraction);
  Serial.print(" pTolerance=");
  Serial.print(pTolerance);
  Serial.print(" rTolerance=");
  Serial.println(rTolerance);

  // retrieve EEPROM AP configuration
  esid = preferences.getString("AP_SSID", "");
  epass = preferences.getString("AP_PASS", "");
  String eap = preferences.getString("AP_IP", "");

  // if EEPROM info is missing, use defaults from config file
  if ((esid == "") && (epass == "")) {
    Serial.println("\nInitial SoftAP user/pass configuration");
    esid = String(configJSON["AP_name"]);
    epass = String(configJSON["AP_pass"]);
    preferences.putString("AP_SSID", esid);
    preferences.putString("AP_PASS", epass);
  }
  if (eap == "") {
    Serial.println("\nInitial SoftAP address configuration");
    eap = String(configJSON["AP_IP"]);
    preferences.putString("AP_IP", eap);
  }

  Serial.print("Access point SSID: ");
  Serial.println(esid);
  Serial.print("Access point PASSWORD: ");
  #ifdef HIDE_PASSWORDS
    Serial.println( "*Hidden*");
  #else
    Serial.println(epass);
  #endif
  Serial.print("Access point ADDRESS: ");
  Serial.println(eap);

  // start our SoftAP with one allowed connection
  WiFi.onEvent(WiFiEvent);
  WiFi.mode(WIFI_AP_STA);
  WiFi.softAPsetHostname(esid.c_str());
  if (!WiFi.softAP(esid.c_str(), epass.c_str(), 1, 0, 1))
  {
    Serial.println("SoftAP creation failed.");
    while (1);
  }
  delay(100);

  IPAddress apIP;
  apIP.fromString(eap);
  IPAddress NMask(255, 255, 255, 0);
  WiFi.softAPConfig(apIP, apIP, NMask);
  myIP = WiFi.softAPIP().toString();
  Serial.print("SoftAP server started at: ");
  Serial.println(myIP);

  // HTML+JS+CSS+Images server callbacks
  // handlers are evaluated in the order they are attached to the server.
  server.onNotFound([](AsyncWebServerRequest * request) {
    request -> send(404, "text/html", "<h1 align=\"center\">Oops! It's not here.</h1>");
  });

  server.on("/", WebRequestMethod::HTTP_GET, [](AsyncWebServerRequest * request) {
    // our van level image page with blocking stack heights
    request -> send(LittleFS, "/index.html", "text/html");
  });

  server.on("/setup", WebRequestMethod::HTTP_GET, [](AsyncWebServerRequest * request) {
    if(!request->authenticate(esid.c_str(), epass.c_str()))
      return request->requestAuthentication();
    request -> send(LittleFS, "/setup.html", "text/html");
  });

  server.on("/setup.html", WebRequestMethod::HTTP_GET, [](AsyncWebServerRequest * request) {
    if(!request->authenticate(esid.c_str(), epass.c_str()))
      return request->requestAuthentication();
    request -> send(LittleFS, "/setup.html", "text/html");
  });

  // server callback for RESTful IMU update readings
  server.on( "/readings", WebRequestMethod::HTTP_GET, [](AsyncWebServerRequest *request){
    Serial.println( "RESTful query");
    String json = getSensorReadings();
    request->send( 200, "application/json", json);
  });

  // server callback button handlers
  server.on("/setupData", WebRequestMethod::HTTP_GET, [](AsyncWebServerRequest * request) {
    Serial.println( "Fetching Offsets");
    String content = String("{\"ver\":\"") + VERSION + "\",\"myIP\":\"" + myIP + "\",\"localIP\":\"" + localIP
                      + "\",\"wsid\":\"" + wsid + "\",\"apname\":\"" + esid
                      + "\",\"p_offset\":\"" + pOffset + "\",\"p_invert\":\"" + pInvert
                      + "\",\"r_offset\":\"" + rOffset + "\",\"r_invert\":\"" + rInvert
                      + "\",\"alpha\":\"" + String(alpha, 3)
                      + "\",\"fraction\":\"" + String(blockFraction, 3)
                      + "\",\"p_tolerance\":\"" + String(pTolerance, 2)
                      + "\",\"r_tolerance\":\"" + String(rTolerance, 2)
                      + "\",\"MAC\":\""+ String( WiFi.macAddress()) + "\"}";
    Serial.println(content);
    request -> send(200, "application/json", content);
  });
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
void loop() {
  ElegantOTA.loop();
  
  if (bootStart != 0) {
    // received a reboot request from the setup page
    if ((millis() - bootStart) > bootDelay) {
      ESP.restart();
    }
  }
  
  // Periodically check Wi-Fi connection and attempt reconnect if disconnected
  if (millis() - lastWifiCheck >= wifiCheckInterval) {
    lastWifiCheck = millis();
    if (WiFi.status() != WL_CONNECTED && wsid.length() > 0 && wsid != "Not Given") {
      Serial.println("Wi-Fi network unavailable or disconnected. Retrying connection...");
      WiFi.disconnect();
      WiFi.reconnect();
    }
  }
  
  // poll IMU at the sensor bandwidth rate
  if ((micros() - lastSensorReadTime) >= sensorReadDelay) {
    updateSensorData();
    lastSensorReadTime = micros();
  }
  
  // update the index page with latest sensor readings
  if ((WiFi.status() == WL_CONNECTED) || apConnected) {
     if ((millis() - lastWebTime) >= webDelay) {
      events.send("ping", NULL, millis());
      events.send(getSensorReadings().c_str(), "new_readings", millis());
      lastWebTime = millis();
    }
  }
}

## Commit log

2026-04-30 Initial commit of source
    [1551KFL Board.DXF, 1551KFL.SLDASM, Adafruit ADXL343 STEMMA QT.STEP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]
2026-04-30 Removed Kicad backups folder
2026-05-01 Fixed POST errors in html, pullup issues in reset function
    Boards without pullup resistors on GPIO0 would reset WiFi credentials every restart. Provided option in code to use INPUT or INPUT_PULLUP depending on dev board used.
    POST was being used for credential settings from setup.html, but was actually appending arguments like GET.
    [Van_Level.ino]
2026-05-01 fixed comment char, bumped version
    [Van_Level.ino]
2026-05-04 moved alpha and fraction to setup values
    changed hardcoded smoothing alpha and leveling block fraction values, to setup/calibration values
2026-05-04 documentation
    still working on getting the documentation ready to publish
    [1551KFL.SLDASM, 3D Printed Washer.STL]
2026-07-10 1.0 Release
    ## Bug Fixes
    - Setup webpage setupData incorrect parsing of myIP value
    - HA REST sensor converted to modern format and added availability to handle packet loss
    - HA Lovelace modified state_not test to check for zero as float
    - App failed to connect to HA clients if started before network was available. STA was being disabled if no network and never re-enabled. Rewrote wifi connection to utilize ESP32 auto reconnect and removed blocking testWifi().
    10
    ## Enhancements
    - Added color notification on webpage and HA dashboard if van is level within tolerance
    [Van_Level.ino]
2026-07-10 level tolerance user configurable
    Split level tolerance into individual pitch and roll values and made them configurable on the setup/calibration tab.
    [Van_Level.ino]
2026-10-30 Significant rewrite
    Robustness and stability upgrade.
    - mutex protection on the IMU data
    - HTML missing parameter protection
    - prevent scanWifi from blocking
    - validate user entries on the setup page
    - replace JSON string concatenation
    - limit visibility of served pages and resources
    - authenticate HTML and encrypt sensitive data
    - wifi changes no longer require reboot
    - fixed wifi not reconnecting when DHCP not available at startup
    - added stale data indication on webpage
    - added status messages to setup page
    - removed linked JavaScript dependencies
    - removed bloated linked css
